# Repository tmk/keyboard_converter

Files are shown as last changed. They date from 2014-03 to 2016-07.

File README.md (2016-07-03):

TMK Keyboard Converter PCB with Mini DIN connector
==================================================
This converts pre-modern keyboard protocols into modern USB using [TMK Keyboard Firmware Collection][tmk_keyboard].

[tmk_keyboard]: https://github.com/tmk/tmk_keyboard

You can buy assembled converter here. https://geekhack.org/index.php?topic=72052.0

Updates
-------
2016/07/03  Rev 2.4 Changed foot print of USB microB and Xtal
2015/09/29  Rev 2.2 Changed LED footprint

Supported Protocols
-------------------
See [this](https://github.com/tmk/tmk_keyboard#converter) for supported protocols.

### PS/2(ScanCode Set 2)
MiniDIN 6P

### Apple Desktop Bus
MiniDIN 4P

### Sharp X68000
MiniDIN 7P

### Sun Type3-5
MiniDIN 8P

### NEC PC98
MiniDIN 8P

### NeXT
MiniDIN 5P

Schematics
----------
[converter_schematic.pdf](converter_schematic.pdf)

PCB Revisions
-------------
### PCB rev1
[Rev1](Rev1.md) has lands for MiniDIN and IO pads for other interface than MiniDIN. With wire jumpers it can support many protocols.
It uses Atmel AVR ATmega32U4.

Rev1 PCB

### PCB rev2
Rev2 is smaller and supports only protocols which uses MiniDIN connector and can be configured with solder jumpers on bottom of the board.
It uses Atmel AVR ATmega32U2.

Rev2 PCB

### PCB rev2.1
Fixed misaligned pins of Mini DIN connector, clearance of solder mask and silk prints.

Rev2.1 PCB

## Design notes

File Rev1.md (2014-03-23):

Keyboard Protocol Converter Board rev1
======================================

PCB rev1
--------
PCB

Configuration
-------------
### MiniDIN connector
Can be installed on the PCB and configured by wiring between MiniDIN Pin1-8 and Port D0-7. This is ADB converter with MiniDIN 4P.

MiniDIN

### Non-MiniDIN connector 
Should be placed outside of the PCB and connected to the Port. This is IBM Termial converter with DIN 5P.

DIN

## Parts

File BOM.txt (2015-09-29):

BOM of TMK Converter Rev.2
--------------------------
J1:             USB Micro-B(Hirose ZX62R-B-5P)
MCU:            ATMega32U2-AU  TQFP
Xtal:           16MHz(FA-238)
LED:            3020 ROHM SML-012WT
SW:             Alps SKRP Push Switch
Capacitors:     10u(or 4.7u), 1u, 0.1u*2, 22p*2(1608)
Resistors:      22*2, 1K*7(1608)
MinDIN:         4P(ADB), 5P(NEXT), 6P(PS/2), 7P(X68K), 8P(SUN/PC98)
                TE Connectivity and MARUSHIN connectors will fit.

* Package size in metric.

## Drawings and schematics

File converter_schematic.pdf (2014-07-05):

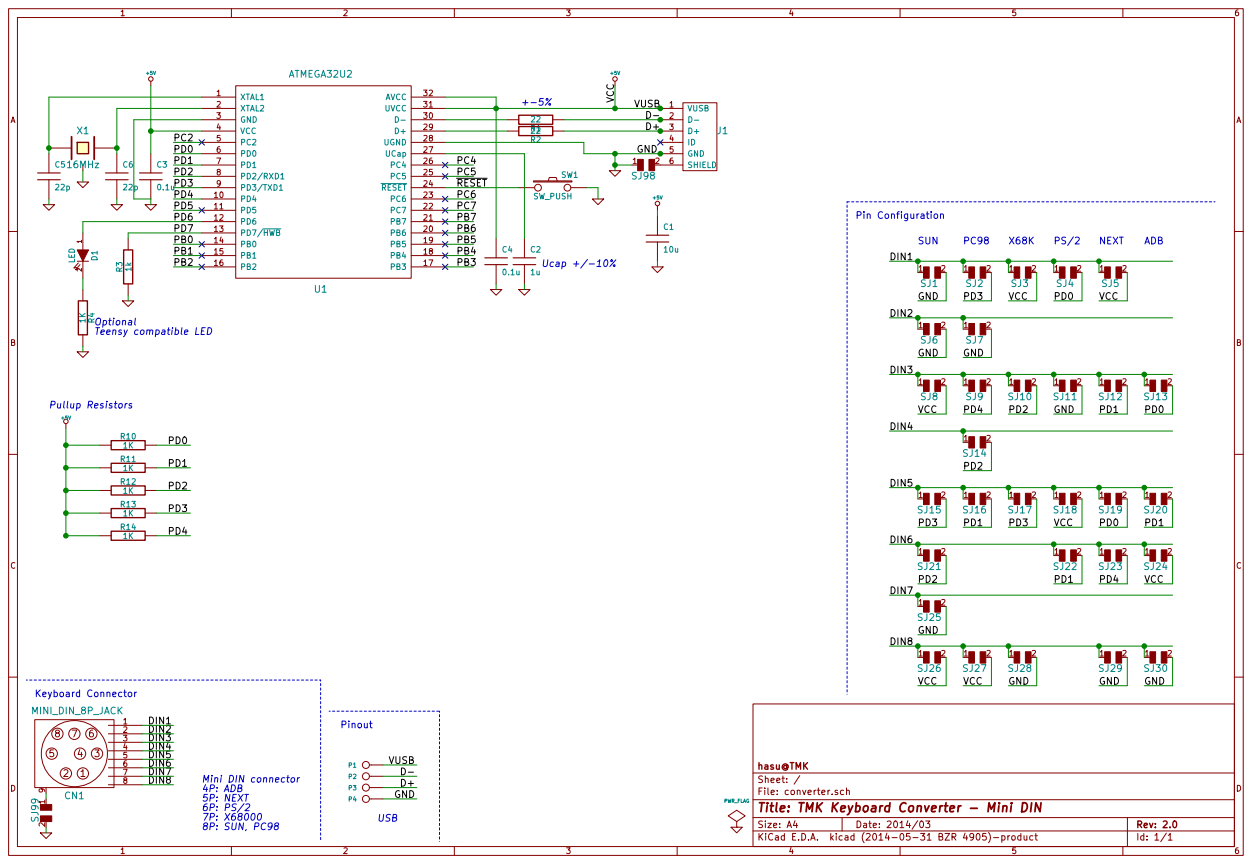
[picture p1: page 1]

File: converter.sch Sheet: / hasu@TMK

Id: 1/1 Title: TMK Keyboard Converter - Mini DIN

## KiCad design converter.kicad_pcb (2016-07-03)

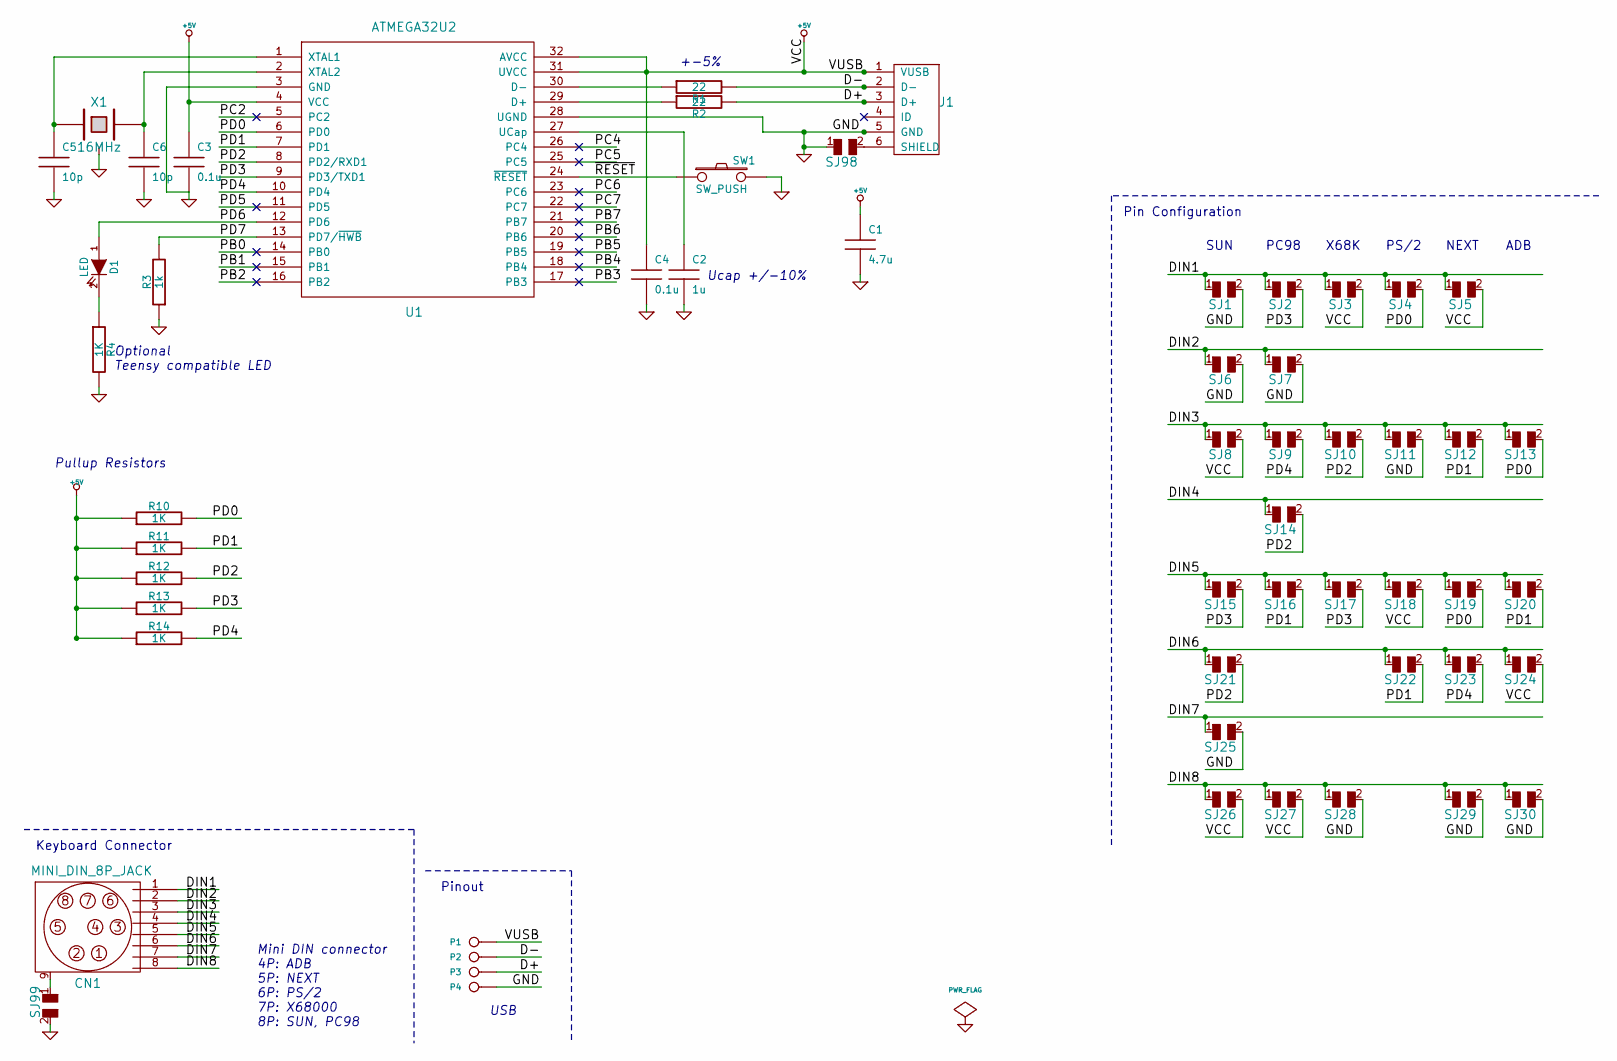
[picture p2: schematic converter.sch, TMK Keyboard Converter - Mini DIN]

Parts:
C1: 4.7u
C2: 1u
C3, C4: 0.1u
C5, C6: 10p
CN1: MINI_DIN_8P_JACK
D1: LED
J1: USB_mini_micro_B
P1, P2, P3, P4: CONN_1
R1, R2: 22
R3: 1k
R4, R10, R11, R12, R13, R14: 1K
SJ1, SJ2, SJ3, SJ4, SJ5, SJ6, SJ7, SJ8, SJ9, SJ10, SJ11, SJ12, SJ13, SJ14, SJ15, SJ16, SJ17, SJ18, SJ19, SJ20, SJ21, SJ22, SJ23, SJ24, SJ25, SJ26, SJ27, SJ28, SJ29, SJ30, SJ98, SJ99: SOLDER_JUMPER
SW1: SW_PUSH
U1: ATMEGA32U2
X1: 16MHz

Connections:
+5V: C1.1, C3.1, C4.1, J1.1 (VUSB), P1.1, R10.1, R11.1, R12.1, R13.1, R14.1, SJ3.2, SJ5.2, SJ8.2, SJ18.2, SJ24.2, SJ26.2, SJ27.2, U1.4 (VCC), U1.31 (UVCC), U1.32 (AVCC)
/D+: J1.3 (D+), P3.1, R2.2
/D-: J1.2 (D-), P2.1, R1.2
/DIN1: CN1.1, SJ1.1, SJ2.1, SJ3.1, SJ4.1, SJ5.1
/DIN2: CN1.2, SJ6.1, SJ7.1
/DIN3: CN1.3, SJ8.1, SJ9.1, SJ10.1, SJ11.1, SJ12.1, SJ13.1
/DIN4: CN1.4, SJ14.1
/DIN5: CN1.5, SJ15.1, SJ16.1, SJ17.1, SJ18.1, SJ19.1, SJ20.1
/DIN6: CN1.6, SJ21.1, SJ22.1, SJ23.1, SJ24.1
/DIN7: CN1.7, SJ25.1
/DIN8: CN1.8, SJ26.1, SJ27.1, SJ28.1, SJ29.1, SJ30.1
/PB0: U1.14 (PB0)
/PB1: U1.15 (PB1)
/PB2: U1.16 (PB2)
/PB3: U1.17 (PB3)
/PB4: U1.18 (PB4)
/PB5: U1.19 (PB5)
/PB6: U1.20 (PB6)
/PB7: U1.21 (PB7)
/PC2: U1.5 (PC2)
/PC4: U1.26 (PC4)
/PC5: U1.25 (PC5)
/PC6: U1.23 (PC6)
/PC7: U1.22 (PC7)
/PD0: R10.2, SJ4.2, SJ13.2, SJ19.2, U1.6 (PD0)
/PD1: R11.2, SJ12.2, SJ16.2, SJ20.2, SJ22.2, U1.7 (PD1)
/PD2: R12.2, SJ10.2, SJ14.2, SJ21.2, U1.8 (PD2/RXD1)
/PD3: R13.2, SJ2.2, SJ15.2, SJ17.2, U1.9 (PD3/TXD1)
/PD4: R14.2, SJ9.2, SJ23.2, U1.10 (PD4)
/PD5: U1.11 (PD5)
/PD6: D1.1 (A), U1.12 (PD6)
/PD7: R3.2, U1.13 (PD7/~HWB)
/~RESET: SW1.1, U1.24 (~RESET)
GND: C1.2, C2.2, C3.2, C4.2, C5.2, C6.2, J1.5 (GND), P4.1, R3.1, R4.2, SJ1.2, SJ6.2, SJ7.2, SJ11.2, SJ25.2, SJ28.2, SJ29.2, SJ30.2, SJ98.1, SJ99.2, SW1.2, U1.3 (GND), U1.28 (UGND), X1.3
unnamed: C2.1, U1.27 (UCap)
unnamed: C5.1, U1.1 (XTAL1), X1.1
unnamed: C6.1, U1.2 (XTAL2), X1.2
unnamed: CN1.9, SJ99.1
unnamed: D1.2 (K), R4.1
unnamed: J1.6 (SHIELD), SJ98.2
unnamed: R1.1, U1.30 (D-)
unnamed: R2.1, U1.29 (D+)

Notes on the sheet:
Pullup Resistors
Mini DIN connector 4P: ADB 5P: NEXT 6P: PS/2 7P: X68000 8P: SUN, PC98
USB
Ucap +/-10%
+-5%
Optional Teensy compatible LED
Keyboard Connector
PC98
X68K
PS/2
NEXT
ADB
SUN
Pin Configuration
Pinout

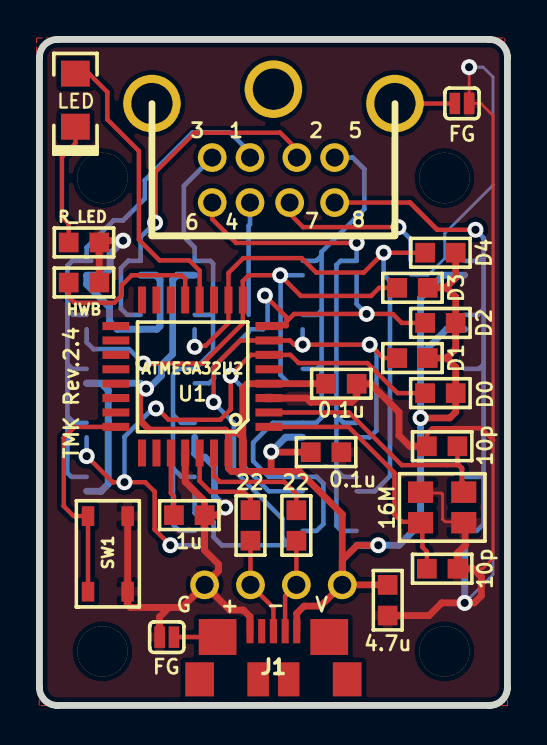
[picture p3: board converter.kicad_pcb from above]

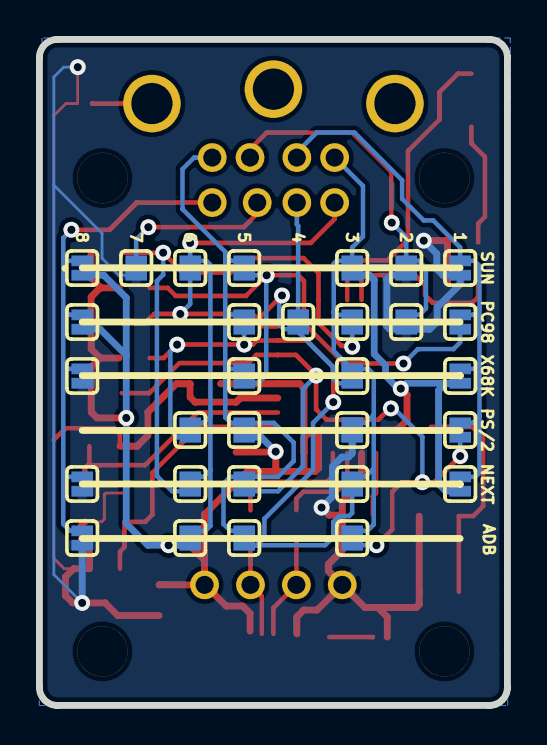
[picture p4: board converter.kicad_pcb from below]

Board: 2 copper layers, 26.0 x 37.0 mm, 61 parts (30 on the bottom side), 28 nets.

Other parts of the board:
HOLE_M2.6, HOLE_M2.6#2, HOLE_M2.6#3, HOLE_M2.6#4: VAL**; HOLE_M2.6

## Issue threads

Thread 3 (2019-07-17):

Micro USB connector pinout reversed

stas2k, 2019-07-17:
Micro USB connector footprint on the board is mirrored causing a short and a swap between D- and ID pins.
I have tried to correct it but could not come up with a good way to route the swapped pins.

tmk, 2019-07-17:
Just make foot print for your component :D
Or just use ZX62R-B-5P.

stas2k, 2019-07-18:
OK, got it! My connector is upside down compared to the one you used.
Good thing about standards is that there are so many to choose from. :D I already have the boards from JLCPCB and the connectors, so I will just do some botch wires.

BTW, thanks for providing the boards here, as soon as my X68K arrives, I will test the adapter.

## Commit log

2013-04-30 Add initial files.
    [$savepcb.brd, converter.brd, converter.dsn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]
2013-05-01 Add converter.mod
    [converter.sch]
2013-05-01 Assign footprint
2013-05-05 Wire component
    [.kicad_pcb.kicad_pcb, converter.dsn, converter.kicad_pcb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]
2013-05-10 Rev1 for fusion PCB
    [$savepcb.brd, .kicad_pcb.kicad_pcb, converter.brd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]
2013-05-22 Clean temp files
    [$savepcb.brd, converter.brd, converter.dsn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]
2013-05-22 Remove wrong 3D model from PIN_1 module
    [converter.kicad_pcb]
2013-05-30 Fix library preference
    [converter.sch]
2013-07-11 Clean up gerber files
    [converter.gbl, converter.gbo, converter.gbs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]
2014-03-23 Initial commit of PCB rev.2
    [converter.kicad_pcb, converter.sch]
2014-03-23 Add rev.2 gerber files.
    [converter.gbl, converter.gbo, converter.gbs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]
2014-03-23 Clean library.
    [converter.kicad_pcb]
2014-03-24 Update Mini DIN module and vix PCB.
    - Wrong pad alignment
    [converter.kicad_pcb]
2014-07-05 Update README.md and add BOM.txt
2014-07-05 Add schematic
2015-09-29 Change LED footprint and add numbering silks
    [converter.kicad_pcb]
2015-12-22 Change values of capacitors and solder mask setting
    [converter.kicad_pcb, converter.sch]
2016-07-03 Add dimensions for pcb edge.cuts
    [converter.kicad_pcb]
2016-07-03 Change foot print of Xtal
    [converter.kicad_pcb]
2016-07-03 Change foot print of USB_microB adding bottom pads
    [converter.kicad_pcb]
